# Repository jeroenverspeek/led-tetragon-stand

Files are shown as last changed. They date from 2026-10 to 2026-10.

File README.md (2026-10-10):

# led-tetragon-stand

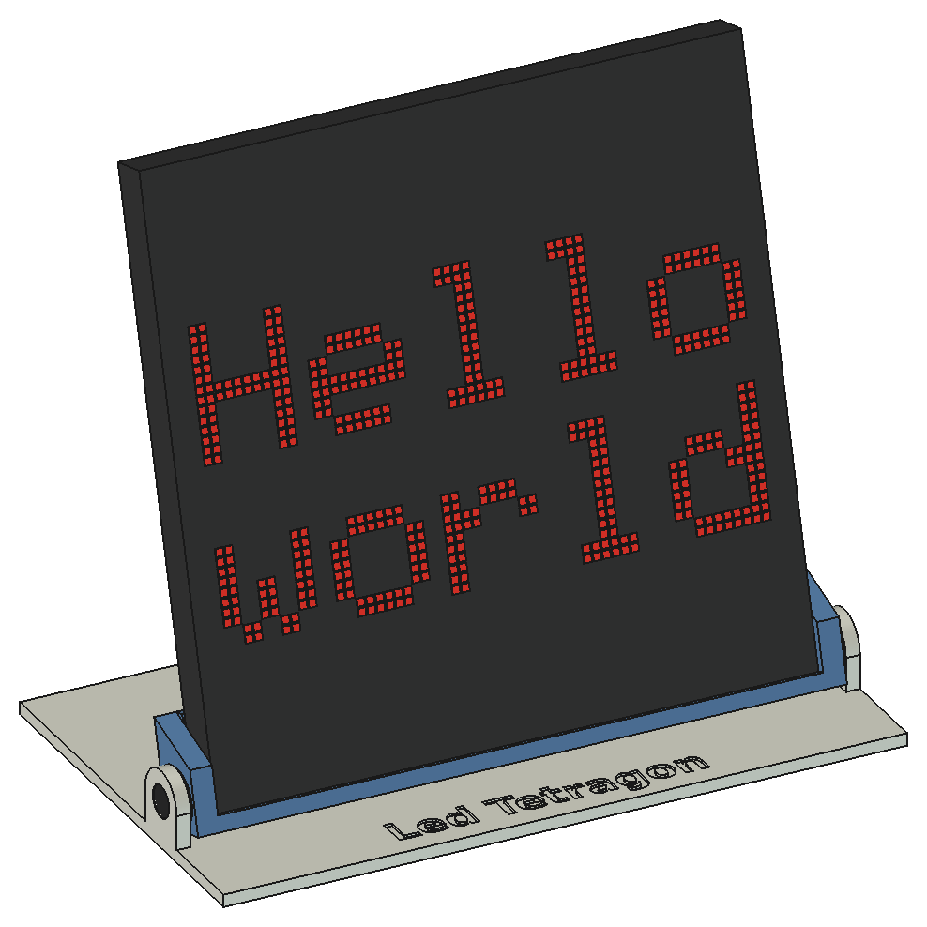
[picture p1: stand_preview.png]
The panel on its stand at 75 degrees

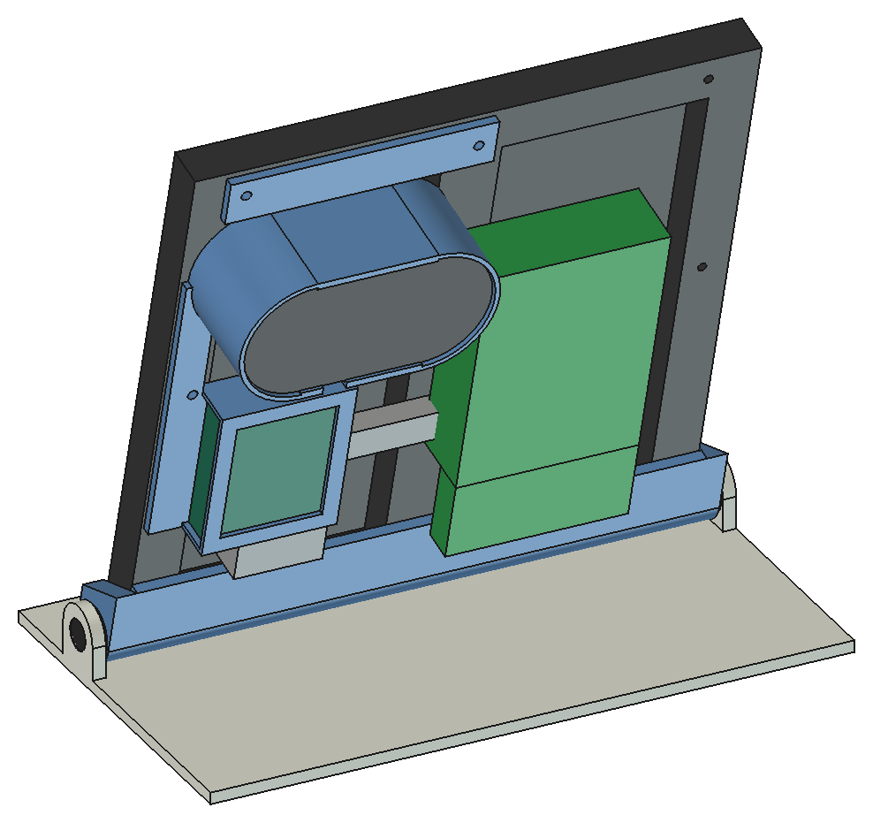
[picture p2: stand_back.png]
The back: the Pi, and the holder with the speaker and the micro:bit


A 3D-printed stand for the LED tetragon: one 64 x 64 P3 LED panel on its
factory frame, with the Raspberry Pi on the back. The panel leans back at an
angle that is set by hand (75 degrees to the table by default) and held by a
friction hinge with two countersunk screws. A holder on the back of the panel
carries the USB speaker and the micro:bit.

Print 1 x `base.stl`, 1 x `cradle.stl` (lying on its floor) and 1 x
`holder.stl` (lying on its plate). Also needed: 2 x M5 x 12 countersunk
screw, 2 x M5 nut and 3 x M3 x 10 screw.

The model is made in FreeCAD 1.x from `build_stand.py`; all dimensions are in
the `Params` spreadsheet in `stand.FCStd`. Run `./build.sh` to build, check
and save the files. See [PLAN.md](PLAN.md) for the design and
[PANEL.md](PANEL.md) for the measurements of the panel.

## Licence

GNU General Public License v3.0, see [LICENSE](LICENSE).

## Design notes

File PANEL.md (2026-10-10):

# The LED tetragon: measurements

Everything measured on the panel and what is fixed to it, in mm. The stand is
built from these; in `build_stand.py` they are in the `Params` spreadsheet,
in `check_stand.py` the ones only used for checking.

Seen from the back means: looking at the back of the panel, standing upright
with the USB ports of the Pi at the top. "From the left" and "from the top"
are then from the edges of the panel. Seen from the front, left and right
swap.

## Panel

- One 64 x 64 LED panel, P3: 192 x 192 mm.
- Front of the LEDs to the back of the factory frame: 14, the LEDs with their
  board 2 and the frame 12.
- Weight with the frame: about 400 g (guess).
- The panel lies a quarter turn round from how it was first mounted; the
  pictures are turned to match in software.

## Frame

- Five bars, all the full 12 deep, their backs flush: four round the edge,
  16 wide, and one up the middle, 20 wide. No other bars, no magnets.
- All holes are M3 with brass inserts; a screw can go all the way in, to the
  LED board.
- Middle bar: 4 holes, evenly spaced, the top one 10 from the top. The Pi is
  on the middle two.
- Left (seen from the back): a hole in each corner, in the top and bottom
  bars, 17 from the left and 8 from the top or bottom; and one in the left
  bar, 9 from the left and 87 from the top. The left bar has a small pin that
  can be snapped off if it is in the way.
- Right: the same holes, mirrored.

## Connectors of the panel

All on the left half, seen from the back.

- HUB75 IN (the lower of the two, the only one used): 26 wide and about 10
  high, its left side 30 from the left, its middle 39 from the bottom. The
  header does not stick out past the bars, but the plug with its cable does,
  further than the power plug (how far is not measured). The ribbon leaves
  the plug upwards and goes over the hat to the lowest of the hat's three
  HUB75 connectors.
- HUB75 OUT: above it, also 30 from the left; not used, not measured.
- Power: 18 wide and 8 high round its middle, 39 from the left and 80 from
  the top. With its plug in it reaches 20 behind the back of the LED board,
  8 past the bars; the cable leaves the plug on the top side.

## Raspberry Pi with the electrodragon hat

- The hat: [RGB matrix panel drive board](https://www.electrodragon.com/product/rgb-matrix-panel-drive-board-raspberry-pi/)
  ([wiki](https://w.electrodragon.com/w/RPI_RMP_HDK)).
- In portrait on the middle two holes of the middle bar, USB ports at the
  top, the USB power port on the right side seen from the back.
- Seen from the back: from 90 from the left to 40 from the right, and from 40
  from the top (the USB ports). The hat sticks out below the Pi, down to 39
  from the bottom.
- Behind the LED board: the Pi's board at 22, the hat's at 33. With about
  3 of solder under the Pi and 9 of parts on the hat (guesses) it reaches from
  7 to 30 behind the frame.
- The feed of the electrodragon board and the Pi's power (via a USB adapter)
  are separate cables.
- Weight with the cables: about 120 g (guess).

## USB speaker

- Kiwi Electronics KW-2835 (HK-5002), the same as Adafruit 3369: one box
  with two drivers, USB audio and power over one USB-A cable of about 1.2 m.
- 84 x 43 x 32, 74 g. The grille is on the flat face, a rectangle with half
  round ends (84 x 43); behind it the body is rounded.
- The cable leaves the bottom side, 33 from the left end of the face (seen
  from the back, grille backwards), pointing down; with its sleeve it needs
  10 below the speaker.
- On the back of the panel: grille backwards, 20 from the top and 5 from the
  left, so its rounded end stays clear of the corner of the Pi.

## micro:bit V2

- 51.6 x 42 x 11.65 (with its parts), about 10 g.
- In a USB port of the Pi with a 20 cm cable. Only tilted together with the
  panel; its buttons are not used.
- Its USB plug with the sleeve sticks out 40 straight from the micro:bit.
- On the back of the panel: upright between the power connector and HUB75
  IN, its USB port towards the Pi, LEDs towards the panel.

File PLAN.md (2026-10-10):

# Stand for the LED tetragon

The tetragon is one 64 x 64 P3 LED panel (192 x 192 mm) on its factory frame.
The Raspberry Pi with the electrodragon hat sits on the back of the frame, in
portrait on the vertical middle bar, USB ports at the top, from the middle to
the right seen from the back. The USB speaker and the micro:bit go in the left
half. All measurements of the panel and what is on it are in
[PANEL.md](PANEL.md).

## Design

The panel leans back at an angle that can be set by hand: anything from lying
flat to upright, held by friction. 75 degrees to the table (leaning back 15
degrees) is the default and a good viewing angle on a desk.

- `Cradle`: a full-width channel that the bottom edge of the panel stands in:
  floor, a 1 mm lip in front, a 28 mm back wall up the back of the frame,
  below the HUB75 IN plug (32 mm up). The panel rests in it by its own
  weight. Ears at both
  ends carry the hinge: a hole, a pocket for an M5 nut on the inside and a
  raised ring on the outside. The corner under the back wall is rounded round
  the hinge axis, so the cradle clears the base at every angle.
- `Base`: plate with a cheek at both ends and "Led Tetragon" sunk in front.
  Each cheek has a countersink on the outside, so the head of the screw lies
  flush. Tightening the screw presses cheek and ring together; that friction
  holds the angle. Set it once with a key or screwdriver so the panel turns
  by hand but stays where it is put.
- `Holder`: one part on three M3 x 10 screws, in the left half seen from the
  back, beside the Pi: the top left corner hole, the top hole of the middle
  bar and the middle hole of the left bar. Prints lying on its plate.
  - Speaker at the top, grille facing backwards, 5 mm from the left so its
    rounded end stays clear of the Pi: a cup on the plate for its rounded
    back, held by a lip along both long sides. The cable leaves the speaker's
    bottom side, 33 mm from its left end, through a slot in the bottom of the
    cup, with 10 mm free below it for its sleeve, 3 mm above the power plug.
    The plate bridges the frame, so the power cable, leaving the power plug
    upwards, bends up under it: 11 mm above the plug. The speaker sticks out
    36 mm behind the frame, the Pi 30 mm.
  - A strip down the left bar, past the power plug, joins it to the micro:bit:
    upright in a pocket, parallel to the panel so it tilts with it, LEDs
    towards the panel, USB port towards the Pi. Just below the power plug (2
    mm), so the HUB75 ribbon has 4 mm below it to bend up over it. The
    micro:bit slides in from the side edge of the panel, and its USB plug,
    through a slot in the side of the pocket, keeps it there. A window in the
    cover shows its back. Sticks out 17 mm.
  - The micro:bit's USB plug, straight, sticks out 40 mm and reaches 6 mm
    under the edge of the Pi; a cable with an angled (90 degree) micro USB
    plug, the cable turning up towards the Pi's USB ports, stays clear.

Why not a prop leg in notches: the stand is so small that 5 degree steps lie
only 4 to 6 mm apart, and a loose prop against the back of the panel slides
unless it is fixed to the panel.

Hardware: 2 x M5 x 12 countersunk screw (90 degree head, any drive), 2 x M5
nut, 3 x M3 x 10 screw. Put the nuts in their pockets before the panel goes
in.

## Files

| File | What |
|---|---|
| `build_stand.py` | Builds all parts. Run `./build.sh` |
| `stand.FCStd` | All parts, parametric: change values in the `Params` spreadsheet |
| `base.stl`, `cradle.stl`, `holder.stl` | For the slicer (1 of each); the cradle prints lying on its floor, the holder on its plate |
| `check_stand.py` | Assembles the stand at 60, 75 and 90 degrees and checks it |
| `stand_preview.FCStd` | The stand with the panel at 75 degrees showing "Hello world", and the holder with the speaker and micro:bit on the back, for looking at only |
| `stand_preview.png`, `stand_back.png` | Pictures of that from the front and from the back, for the README |
| `set_view.py` | Makes the two FreeCAD files open with the model in view |
| `build.sh` | Build, check and view settings in one go |
| `PANEL.md` | All measurements of the panel, the Pi, the speaker and the micro:bit |

The base (218 x 130 mm) only just fits the 220 x 200 mm bed.

## Measured and decided

The measurements themselves are in [PANEL.md](PANEL.md).

- `lip_height` 1 mm is fine.
- The back wall of the cradle was 40 mm high; the HUB75 IN plug, 32 mm up,
  sticks out behind the frame, so it is 28 mm now. That clears the hat too
  (it comes down to 39 mm, 19 mm behind the frame).
- Countersunk screws instead of knobs. From the outside of a cheek to the
  inside of an ear is 12.5 mm, so the screws are M5 x 12; a longer one
  reaches into the panel (a 19 mm one by 7 mm), so cut it to 12 mm. Making
  cheek and ear thicker instead would make the base too wide for the bed.

## Still guessed

- The weight of the panel (400 g) and the Pi (120 g): only used to check that
  the stand does not tip.
- The shape of the speaker's rounded back (from pictures); the cup only holds
  it by its flat face and leaves room behind it.
- How far the parts on the Pi and the hat stick out.
- How far the HUB75 IN plug sticks out and how much bigger it is than the
  header (12 mm and 2 mm all round). The cradle, the holder and the ribbon's
  bend depend on it.

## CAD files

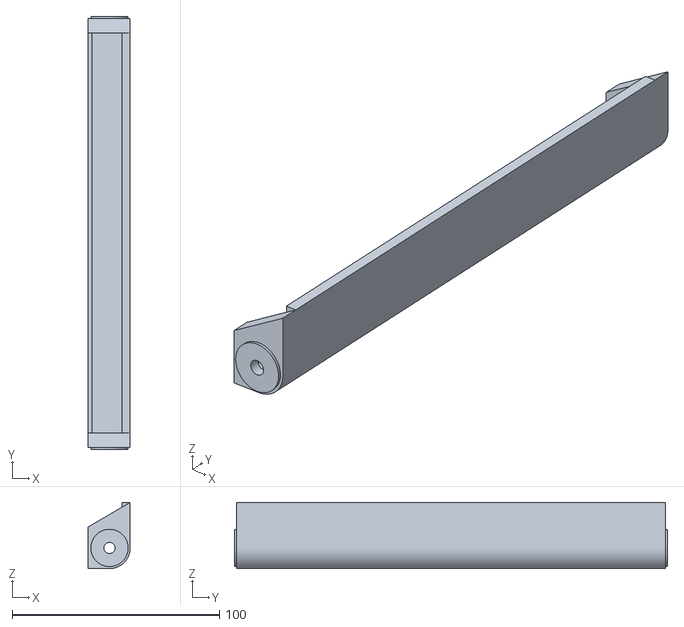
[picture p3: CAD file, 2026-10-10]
cradle.stl
20.5 x 209.0 x 32.0

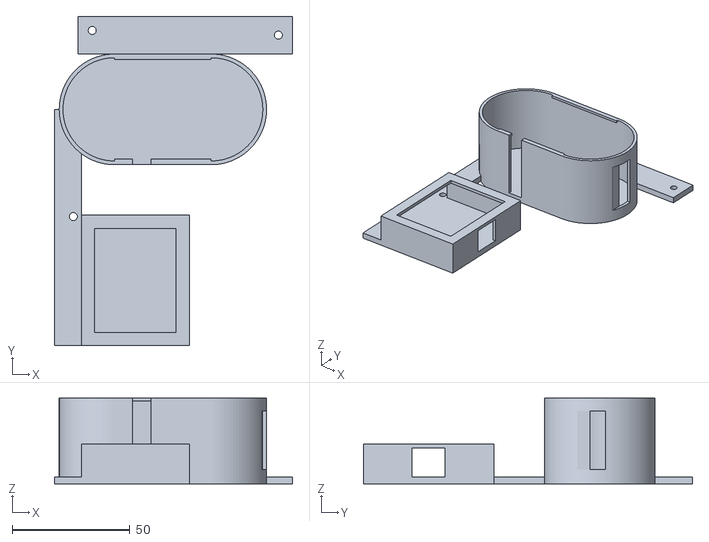
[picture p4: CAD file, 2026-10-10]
holder.stl
101.0 x 139.8 x 36.4

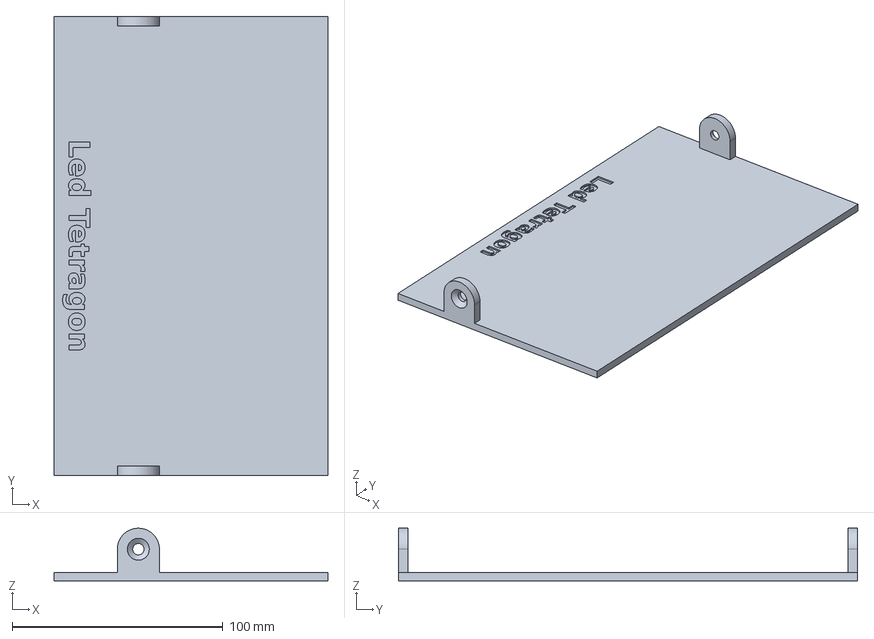
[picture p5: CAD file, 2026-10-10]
stand.FCStd
130.0 x 218.0 x 25.0 mm

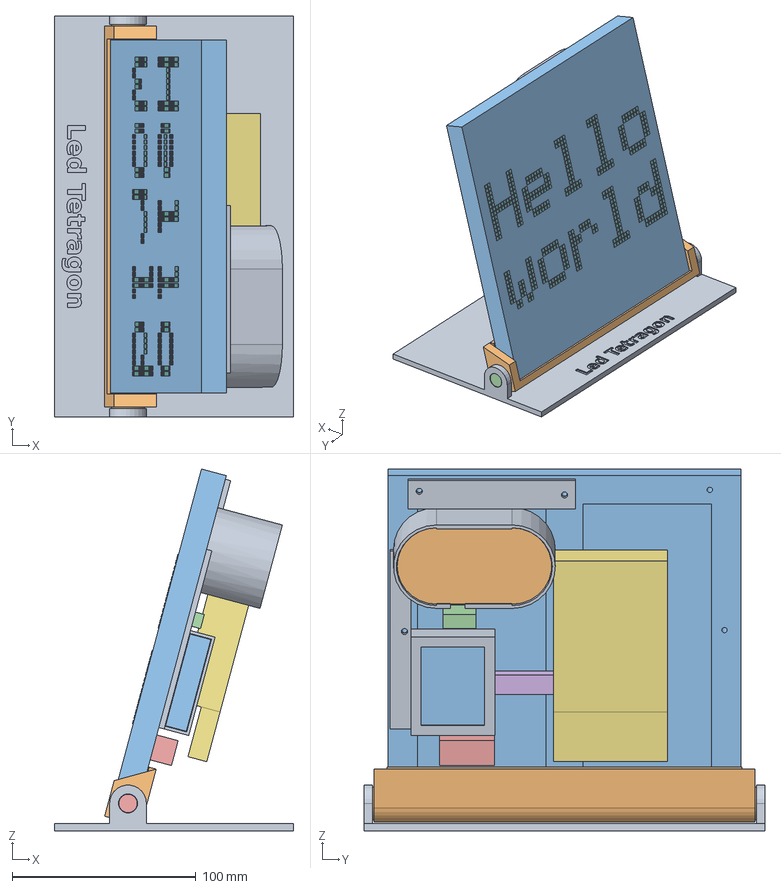
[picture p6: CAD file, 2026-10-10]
stand_preview.FCStd
130.0 x 218.0 x 196.9 mm
Base
Cradle
Panel
PowerPlug
Hub75Plug
MicrobitPlug
Pi_outline
LEDs
Holder
Speaker
Microbit
Screw1
Screw2

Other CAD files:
base.stl

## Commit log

2026-10-08 Stand for the LED tetragon: a cradle on a friction hinge, adjustable angle
    The panel on its factory frame stands in a full-width cradle that leans
    back on a hinge in two cheeks of the base. Two knobs on M5 x 16 bolts
    clamp each ear against its cheek; that friction holds the angle, 75
    degrees to the table by default. The corner under the cradle is rounded
    round the hinge axis, so it clears the base at any angle. Parametric in
    FreeCAD (Params sheet in stand.FCStd), built by build_stand.py; the
    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
    [base.stl, cradle.stl, knob.stl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]
2026-10-10 Countersunk M5 x 12 screws instead of knobs; Hello world on the preview
    The heads sink flush into the cheeks, which are 0.5 mm thicker for it, so
    the knobs are gone. The README picture is smaller and shows Hello world in
    LED pixels on the panel. The bed check now also tries a 90 degree turn.
    [base.stl, knob.stl, stand.FCStd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]
2026-10-10 Holder for the USB speaker and the micro:bit on the back of the panel
    A plate screwed into the top hole of the middle bar, ribs on both sides of
    the bar, a pocket for the micro:bit lying flat and a cup for the speaker
    with its grille backwards. The check now has the Pi and hat where they are
    mounted (portrait, on the middle bar) and a picture from the back.
    [holder.stl, stand.FCStd, stand_preview.FCStd]
2026-10-10 One holder on three screws for the speaker and the micro:bit; the frame in the model
    The speaker sits 5 mm from the left, clear of the Pi, its cable through a
    slot in the bottom of the cup. A strip down the left bar joins it to the
    upright micro:bit, between the power plug and HUB75 IN. The panel is now
    modelled as its LED board and five frame bars with their holes, with the
    power and HUB75 IN plugs; the back wall of the cradle is 28 mm, below the
    HUB75 plug. PANEL.md keeps all measurements of the panel.
    [cradle.stl, holder.stl, stand.FCStd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]
2026-10-11 Panel connectors measured from photos; power connector aligned, holder moved
    Two photos of the back of the panel are added in photos/: one straight
    with a tape measure, and one flattened to the square of the panel with
    the Genius Scan app, in which the panel itself gives the scale.
    photos/grid.py cuts a region out of the flattened photo and draws a
    millimetre grid over it; PANEL.md explains how.
    From the photos: the HUB75 connectors are 16-pin box headers of 28 x 9
    mm (not 26 x 10), the power connector is 16.5 mm wide (not 18) with its
    snap-clip on the top side. HUB75 OUT is described: the same connector
    in the top corner. The power connector's left side is 40 mm from the
    left, and from the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
2026-10-11 M3 holes of the frame measured from the flattened photo
    The brass inserts lie flush with the back of the frame, so the flattened
    photo has no parallax there; the holes on the left and the right agree to
    within 0.5 mm. The hand measurements were 1-1.5 mm off.
    The corner holes are 16 from the side (not 17) and 8 from the top or
    bottom. The middle bar's holes are 9 from the top and the bottom (not
    10), evenly spaced. The hole in the left bar is 8 from the left and 88.5
    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
2026-10-11 Link to the led-tetragon software
    The README says that the software that drives the panel is in
    led-tetragon, with a link.
2026-10-11 PLAN.md becomes DESIGN.md; measured, decided and guessed in PANEL.md
    The sections "Measured and decided" and "Still guessed" move from the plan
    to PANEL.md, next to the measurements they come from. PLAN.md is renamed to
    DESIGN.md, as in the led-hexahedron-stand; the README links to it.
2026-10-11 PRINTING.md: printer, slicer, levelling and how the parts lie on the bed
    The printer is a Creality Ender 3 v2 with Ultimaker Cura, PLA at 60 °C bed
    and 200 °C nozzle. The bed is levelled with Ender3_LEVEL_psd.gcode from the
    printer's SD card. Each part lies on the bed as its STL file is written: the
    base on its plate, the cradle on its floor turned 24 degrees across the
    diagonal, the holder on its plate. Then what to do after printing.
    Almost horizontal surfaces gave steps on the first stand of the cube;
    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
2026-10-11 PRINTING.md: where the levelling G-code comes from
    Ender3_LEVEL_psd.gcode is one of the "Creality Leveling Cycle GCodes" by
    psdesign (Peter Solomon) on Thingiverse, thing 4761680, licensed CC BY. It
    was found through the description of BV3D's Ender 3 v2 unboxing video.
    The file itself is still on the printer's SD card; it can be added here
    later, with this credit.
2026-10-15 Preview: two USB cables out of the Pi's ports
    Two USB-A plugs in the Pi's USB ports, for the speaker and the micro:bit,
    stay 15 mm below the top edge of the panel; their stiff cables go straight
    up out of them and stick out about 50 mm above it before they bend over
    backwards. Checked: the plugs below the edge, plugs and cables clear of
    the holder and the speaker. Port positions from the Pi 4's drawing; plug
    sizes, the cables and which ports are used are guesses (PANEL.md). The
    pictures for the README are left as they were.
2026-10-15 Preview: the Pi's USB-C power cable, as the USB cables
    A USB-C plug in the port on the Pi's right side seen from the back, 11.2 mm
    from its bottom end, out to the right: it stays 15 mm within the right
    edge of the panel, and its stiff cable goes on straight past it, about 50
    mm, before it bends over backwards. One function makes the stiff cables,
    the USB ones up past the top and this one out past the right. Checked: the
    plug within the edge, all plugs and cables clear of the holder, the
    speaker and the frame. The plug and the cable are guesses (PANEL.md); the
    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
2026-10-24 Holder: slots for two screws, a cable tie for the speaker After the first print. Only the top left corner hole is round now; the holes in the middle bar and the left bar, 80 mm from it, are slots 2 m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
    The speaker lay loose under its lips. A cable tie now loops through an
    eye on both long sides of the cup and twice over the middle of the grille,
    in a notch 1 mm below the face, pressing it onto the plate; the eyes print
    without support. A notch at both round ends lets a screwdriver lever it
    out.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
2026-10-24 Holder: the micro:bit on posts, screwed through its GND ring The micro:bit lay loose in its pocket. Now it lies on four posts on its plate, LEDs still towards the panel, 6 mm up so its buttons stay 1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
    Measured from new photos in photos/: the front of the micro:bit flattened
    to its own outline, 51.6 x 42 (rings 0 and GND 43.4 apart, 6.55 from the
    edge, holes 4.0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
2026-10-24 The levelling G-code for the bed Ender3_LEVEL_psd.gcode, until now only on the printer's SD card, with a header crediting psdesign (Peter Solomon), "Creality Leveling Cycle GCodes", https://www.thing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
2026-10-24 PRINTING.md: bed 60 °C in Cura, no build plate adhesion
    Cura's PLA profile sets the bed to 50 °C; Build Plate Temperature has to
    be set to 60. Build Plate Adhesion Type is None for every part: the start
    G-code's purge lines prime the nozzle. With a skirt the base was 220 mm
    wide, the whole bed, and the skirt crossed the purge lines; without one it
    lies from X 1 to 219.
2026-10-24 Base: 0.3 mm play between the cradle's rings and the cheeks
    The rings on the ears were exactly as far apart as the inner faces of the
    cheeks, 209 mm, so the printed cradle did not go in between the cheeks of
    the first base. Now each cheek stands 0.3 mm off its ring (hinge_play):
    209.6 mm between the cheeks. The cheeks are 4.2 mm instead of 4.5, so the
    base stays 218 mm wide and fits the bed as before. Tightening the screw
    bends the cheek onto its ring; then the M5 x 12 ends flush with the inside
    of the ear, 4.2 mm through the nut, and 1.7 mm of cheek is left under the
    countersink.
    The cradle is unchanged; measured on the print, 8.0 mm from the inside of
    an ear to the face of its ring at bot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
2026-10-25 Hinge: an M5 spring washer at one end takes up the play
    On the printed stand the rings had 1 mm of play in total between the
    cheeks instead of the modelled 0.6 (hinge_play 0.3 a side). Tightening the
    screws did not bend the cheeks onto the rings, and the panel turned freely
    and fell flat. An open M5 spring washer of 1.5 mm between a ring and its
    cheek at one end takes up the play; with the screws tightened firmly the
    panel holds its angle, and the washer keeps pressing as the PLA gives way.
    At that end the M5 x 12 ends about 1.5 mm short of the inside of the ear,
    still about 2.5 mm into the nut.
    The washer is in the hardware list and the steps after printing. The
    model is unchanged; a comme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
2026-10-29 Stand for the 128 x 128 panel, at a fixed 75 degrees
    A second stand, for a 128 x 128 LED panel of 24 x 24 cm (P1.875). The
    panel leans back a fixed 15 degrees from upright (tilt), 75 degrees to the
    table: the channel of the 64 x 64 cradle (floor, 1 mm lip, 28 mm back
    wall, an ear at both ends) is built tilted onto a 249 x 130 x 5 mm base
    plate, the space under its floor filled, so it prints on its plate without
    support. One part, no hinge and no screws; "Led Tetragon" sunk in front.
    It is 249 mm wide: stand128.stl in one piece for the Bambu Lab X2D (256 x
    256 mm), or stand128_left.stl and stand128_right.stl for the Ender 3 v2,
    glued. The joint goes between the words of the name; four doveta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
2026-11-01 Converter on the 128 stand: posts 1.5 mm further apart, M2.5 screws
    The 100.6 mm from end to end, scaled from the datasheet's drawing, was 1 to
    1.5 mm short on the printed stand: mount_along is now 102.1 mm. M3 screws did
    not go into the 2.6 mm holes in the posts; M2.5 screws fit tight and hold. The
    openings in the flanges are U-shaped slots, not half round.
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
